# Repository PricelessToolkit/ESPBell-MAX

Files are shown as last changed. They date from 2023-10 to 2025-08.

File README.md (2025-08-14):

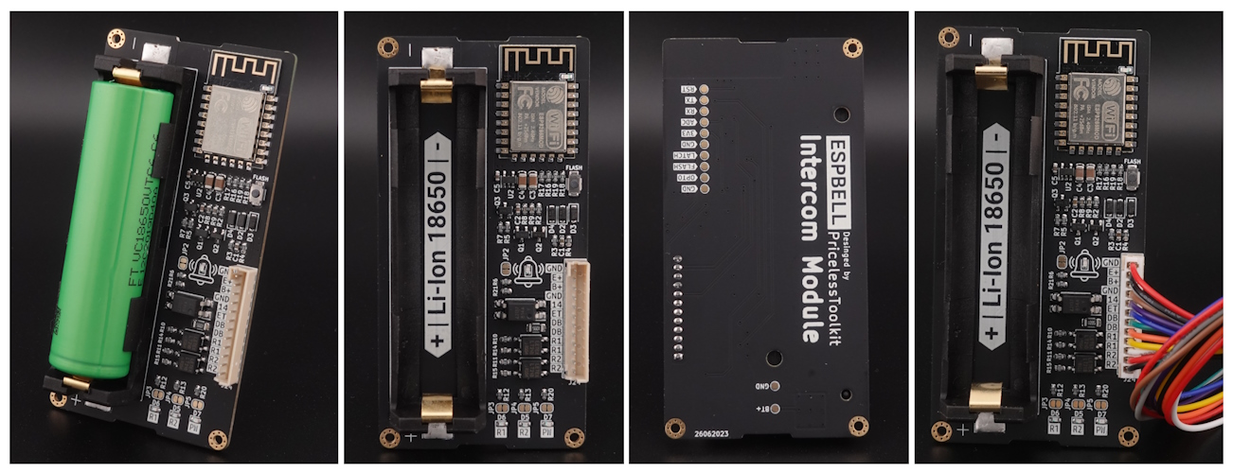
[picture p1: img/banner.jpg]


🤗 Please consider subscribing to my [YouTube channel](https://www.youtube.com/@PricelessToolkit/videos)
Your subscription goes a long way in backing my work.



# ESPBell-MAX and [ESPBell-LITE](https://github.com/PricelessToolkit/ESPBell-LITE)
ESPBell-MAX "IoT Intercom / Doorbell" module enables you to stay informed whenever someone rings your doorbell or presses the intercom button. Upon receiving an interactive notification, you have the convenience to either promptly open the door or choose to dismiss the alert by simply tapping the button within the notification. See the screenshot below.
<details>
  <summary>Notification Screenshot</summary>
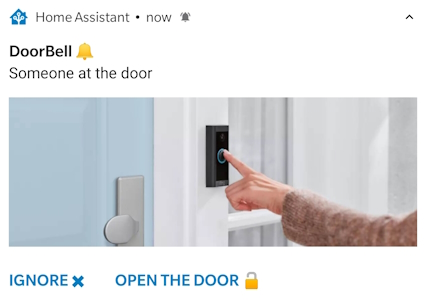
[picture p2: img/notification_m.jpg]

</details>

### _Supported software and future plans_
Currently supported `Home Assistant` and `MQTT` If I have time I'll add control by `Telegram` and `WhatsApp`

### Links

- YouTube video [How To](https://youtu.be/-lQ_mbuilic)
- My Shop
  - [ESPBell-MAX](https://www.pricelesstoolkit.com/en/projects/37-espbell-max-intercom-doorbell-module-0741049314467.html)
  - [UNIProg Programmer](https://www.pricelesstoolkit.com/en/projects/33-uniprog-uartupdi-programmer-33v.html)
- Aliexpress
  - Pogo pin Clamp Fixture
    - https://s.click.aliexpress.com/e/_Dm3ox9R
  - Battery
    - https://s.click.aliexpress.com/e/_DCEo23d
    - https://s.click.aliexpress.com/e/_DCRn6r5
  - Charger
    - https://s.click.aliexpress.com/e/_DeroSfz
    - https://s.click.aliexpress.com/e/_DmU1DXv
  - Vis and Insert "Optional for 3D Case"
    - 3 x Vis M2 4mm - https://s.click.aliexpress.com/e/_DFzWgSp
    - 3 x Insert M2(OD 3.2mm length 3.5mm) - https://s.click.aliexpress.com/e/_DkM0Kfb
  - Cable and connector
    - 1 x 12 Pin PH2.0mm cable https://s.click.aliexpress.com/e/_DdG8cCl
    - 1 x 12 Pin PH2.0mm connector "Straight" https://s.click.aliexpress.com/e/_DDWbwM5

____________

## Specifications
- Based on ESP12F "Programmable via pads on the PCB"
- Power consumption
  - Standby mode: 0.08mA "Per Month!"
  - When triggered: 21uA/s
- Input / Output
  - 2 x "R1/R2" SSR 2.4A 30v Max
  - 1 x "DB" Input Optocoupler 2-30v AC/DC Max "For Doorbell"
  - 1 x "ET" Input 3.3-5v DC Max "External Trigger"
  - 1 x "B+" Battery Voltage "Permanent output"
  - 1 x "E+" Battery Voltage "When ESPBell is enabled"
  - 1 x "GPIO14" 3.3v DC MAX
  - 2 x GND "Only! for ET/B+/E+/GPIO14"
- Status LEDs - Can be deactivated "PCB Jumper"
  - 1 x R1
  - 1 x R2
  - 1 x DoorBell
  - 1 x Power
  - 1 x On ESP module "Not used"
- Battery type Li-Ion 18650
- Button for flashing Firmware

____________

## 📣 Updates, Bugfixes, and Breaking Changes

> [!NOTE]
>  If you're ready to contribute to the project, your support would be greatly appreciated. Due to time constraints, I may not be able to quickly verify new "features" or completely new "code" functionality, so please create a new code/script in the new folder.

- **25.07.2024** - "Voltage divider resistor R8 is 100K or 42.2K"
  ```c
  // Battery Voltage Calculation
  // Orders before 15.07.2024 Please check the voltage divider value. "Marking on the resistor R8"
  
  // If "01D" R8 = 100K"
  int batteryPercentage = map(adcValue, 300, 410, 0, 100); // "Voltage divider R8-100K"
  
  // If "61C" R8 = 42.2K"
  int batteryPercentage = map(average, 670, 880, 0, 100);; // "Voltage divider R8-42.2K"
  ```

____________

## Before you start

> [!NOTE]
> ✅ Please [check your Intercom type.](https://www.intercomsrus.com/finder/) It needs to be a 5-wire intercom system.
> I hope that everything is crystal clear as I've made every effort to provide a step-by-step explanation of the setup process. If you have any further questions regarding the setup or require assistance with assembling a printed circuit board, feel free to join our [Facebook Group](https://www.facebook.com/groups/pricelesstoolkit) or open a new [discussion](https://github.com/PricelessToolkit/ESPBell-MAX/discussions) topic in the dedicated tab.

> [!IMPORTANT]
> If you're new to Arduino-related matters, please refrain from asking basic questions like "how to install Arduino IDE". There are already plenty of excellent tutorials available on the internet. If you encounter any issues, remember that providing detailed information about the problem will help me offer more effective assistance. More information equals better help!

> [!WARNING]
> I would strongly advise against attempting to assemble this PCB on your own if you have no experience "0%" in soldering, or working with ESP / Arduino boards.
> Connecting ESPBell-MAX to your intercom or doorbell demands a certain level of electronics expertise and the proficiency to utilize a multimeter effectively. Please be aware that I cannot assume responsibility for any errors or issues that may arise. My role is to provide guidance and advice to the best of my abilities.

____________

## PCB Assembly
This project is open-source, allowing you to assemble ESPBell-MAX on your own. To simplify this process, I've provided an "Interactive HTML Boom File" located in the PCB folder. This interactive file helps you identify where to solder each component and polarity, reducing the chances of errors to a minimum. But if you don't feel confident in assembling it yourself, you can always opt to purchase a pre-assembled board from my [Shop](https://www.pricelesstoolkit.com)

____________

## Schematic
<details>
  <summary>View schematic. Click here</summary>
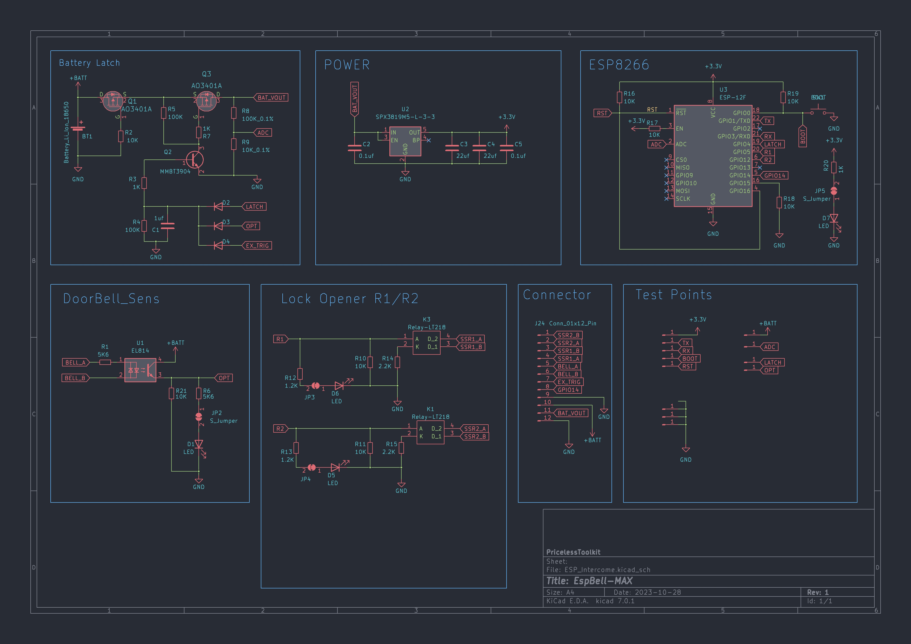
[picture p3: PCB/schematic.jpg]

</details>

____________

## Arduino IDE Configuration
### Used Arduino Libraries
```c
#include "ESP8266WiFi.h"
#include <PubSubClient.h>
```

If you are using ESP8266 for the first time, you need To install the ESP8266 board and PubSubClient library in your Arduino IDE.
- In your Arduino IDE, go to File> Preferences.
- Enter `http://arduino.esp8266.com/stable/package_esp8266com_index.json` into the “Additional Boards Manager URLs” field. Then, click the “OK” button
- Open the Boards Manager. Go to Tools > Board > Boards Manager.
- Search for ESP8266 and press the install button for the “ESP8266 by ESP8266 Community“
- Search for PubSubClient and press the install button.

For board configuration in IDE, see the screenshot below
<details>
  <summary>Board config Screenshot</summary>
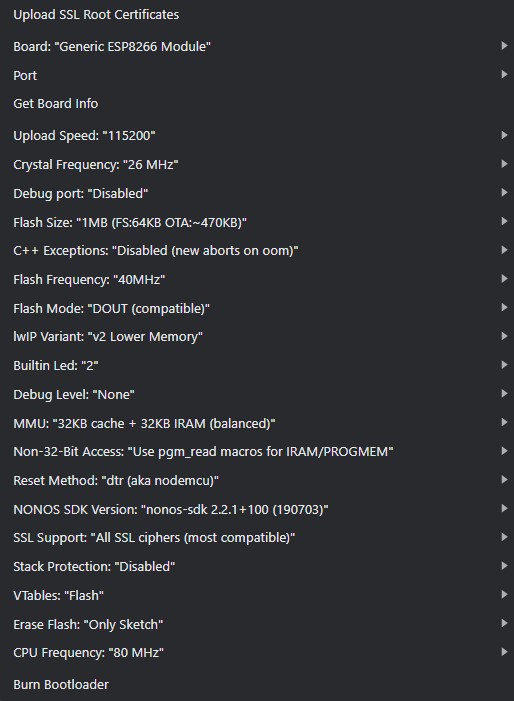
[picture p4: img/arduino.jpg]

</details>

____________

## ESPBell-MAX MQTT sketch configuration

> [!NOTE]
> For `ESPBell-MAX_MQTT_Auto_Discovery.ino`
> all configurations are done in the file `config.h`

### _WI-FI Settings_
To ensure a rapid Wi-Fi connection, we skip the Wi-Fi scanning process. Instead, we simply provide the access point's name, channel, and MAC address. This efficient method significantly shortens the connection time to the access point, taking just about 300 milliseconds.

> [!IMPORTANT]
> Make sure to set a fixed channel on your Wi-Fi access point.

```c
#define WIFI_SSID "Your_WIFI_SSID"
#define WIFI_AUTH "Your_WIFI_Password"
#define DATA_WIFI_CH 6 // Put your Wi-Fi channel and disable channel hopping in your WI-FI Access Point
#define DATA_WIFI_BSSID {0xAA, 0xAA, 0xAA, 0xAA, 0xAA, 0xAA} // Change only AA part.
```
### _Local Network Settings_
As the DHCP-based IP address assignment may introduce certain delays, we can optimize the process by manually assigning and registering the IP address.
> [!IMPORTANT]
> Use IP address outside of DHCP Range.

```c
// IP address, network mask, Gateway, DNS
#define DATA_IPADDR IPAddress(192,168,99,2) // Use IP address outside of DHCP Range 
#define DATA_IPMASK IPAddress(255,255,255,0)
#define DATA_GATEWY IPAddress(192,168,99,1)
#define DATA_DNS1   IPAddress(192,168,99,1)
```
### _MQTT Settings_
Fill in Mosquitto broker credentials and IP address.

```c
const char* mqtt_username = "Your_MQTT_Username";
const char* mqtt_password = "Your_MQTT_Password";
const char* mqtt_server = "IP_Address_of_MQTT/HomeAssistant";
const int mqtt_port = 1883;
```
### _Timing Settings_
Optimal performance and energy efficiency hinge upon these configurations, consisting of three critical parameters. It's important to note that 1000ms equates to 1 second.
<details>
  <summary>Explanation click here</summary>
upTime: This variable represents the time delay, in milliseconds, before initiating a 'Power Off' operation by setting the Latch PIN to LOW. You can adjust this value to determine how long the system should wait after waking up before powering down.

openTime: This variable sets the duration, in milliseconds, during which the relays remain active. Modify this value to control how long the relays stay on.

autoOff: This parameter can be set to either 0 or 1:
- 0: DISABLED - ESPBell will power down after the 'upTime' specified.
- 1: ENABLED - ESPBell will automatically power down after the 'openTime' has elapsed.
</details>

> [!IMPORTANT]
> When using ESPBell-MAX with an intercom system select your 'upTime' value carefully to ensure you have sufficient time for picking up your phone, checking notifications, and pressing the action button, along with a little extra time in reserve for added convenience. In the doorbell setup 2s 'upTime' is more than enough.

```c
// 1000 = 1s"
const long upTime = 15000;  // How long to wait after wakeup before powering off "Latch PIN to LOW" 
const long openTime = 2000;  // How long relays is on.
const int autoOff = 1; // 0 = DISABLE / 1 = ENABLE // Powering off automatically after "openTime" // if is set to 0 ESPBell will power down after upTime.
```

____________

## Uploading the Arduino sketch
To upload the sketch into ESPBell-MAX you will need two things.
- Regular USB-TTL 3.3v adapter. I have [open-source USB-TTL](https://github.com/PricelessToolkit/UNIProg_Programmer) project, in case you don’t have a TTL adapter yet and want to assemble it yourself.
- Pogo pin Clamp Fixture "single row 6 Pin 2.54mm spacing" or you can solder wires directly to ESPBell-MAX for programming.

### _USB-TTL Wiring diagram_

| USB-TTL | ESPBell-MAX |
| --- | --- |
| TX | RX |
| RX | TX |
| GND | GND |
| 3.3v | 3.3V |

You need to put the ESPBell-MAX into download mode to upload the firmware, for that, press and hold the Flash button on the ESPBell-MAX, then plug in the USB and press the upload button in Arduino IDE, Don't release the Flash button until you see the upload progress.
____________

## Home Assistant Configuration
> [!NOTE]
> After connection, Home Assistant will automatically  discover ESPBell-MAX with 3 sensors.
> - Bell    | Statuses is OPEN / CLOSE
> - RSSI    | in dBm
> - Battery | in percent 0-100% "3.2-4.2V"
> Because the ESP8266 ADC is inaccurate, measurements can fluctuate.

Here is a multi-user configuration example, which means that a notification is sent to several family members. If one family member clicks on the notification, the notification disappears from the other phones. For all this to work we need to create "three" automation, but before that, in this example, you need to change a minimum few things.
- Image file path that is used as a background for Notification.
- The name of the mobile device that is connected to the Home Assistant. In my case, it's "doogee_v20pro" and "Second_Phone"
  
```yaml
  image: /media/local/notify/doorbell.jpg
- service: notify.mobile_app_doogee_v20pro
- service: notify.mobile_app_Second_Phone

```

### _Automation 1_
This automation sends an interactive notification with the "tag: intercom" to phones.

<details>
  <summary>Explanation click here</summary>
  Alias: This is a user-defined name or label for the automation. In this case, it's given the name "🔔 Intercom DoorBell Notification," which suggests that it's related to receiving notifications for an intercom or doorbell event.

Description: This field is left empty, so there's no additional description provided for this automation.

Trigger: The trigger specifies the event or condition that will start the automation. In this case, it is triggered when the state of the "binary_sensor.espbell_max_bell" changes to "on." This implies that the automation will run when the binary sensor named "espbell_max_bell" switches from an off state to an on state.

Condition: There are no additional conditions specified. This means the automation will proceed without any additional conditions beyond the trigger.

Action: The action section defines what should happen when the trigger condition is met. In this case, there are two actions defined:

The first action uses the "notify.mobile_app_doogee_v20pro" service to send a notification to a mobile device. The notification includes a message "Someone at the door" and is configured with various data attributes, including a persistent notification, high importance, a specified channel ("intercom"), and a tag ("intercom"). It also includes an image file path for the notification and two actions that can be taken by the recipient: "Ignore ✖" and "Open The Door 🔓." The title and message of the notification are also specified in two languages (English and French).

The second action is similar to the first but uses the "notify.mobile_app_Second_Phone" service to send the same notification to another mobile device.

Mode: The mode is set to "single," which means that the automation will only run once for each trigger event. Subsequent trigger events will not cause the automation to run again until the current execution has been completed.
</details>

```yaml
alias: 🔔 Intercom DoorBell Notification
description: ""
trigger:
  - platform: state
    entity_id:
      - binary_sensor.espbell_max_bell
    to: "on"
condition: []
action:
  - service: notify.mobile_app_doogee_v20pro
    data:
      message: Someone at the door
      data:
        persistent: true
        importance: high
        channel: intercom
        tag: intercom
        image: /media/local/notify/doorbell.jpg
        actions:
          - action: intercom_ignore
            title: Ignore ✖
          - action: intercom_open
            title: Open The Door 🔓
      title: DoorBell 🔔
      message: Quelqu'un à la porte
  - service: notify.mobile_app_Second_Phone
    data:
      message: Someone at the door
      data:
        persistent: true
        importance: high
        channel: intercom
        tag: intercom
        image: /media/local/notify/doorbell.jpg
        actions:
          - action: intercom_ignore
            title: Ignore ✖
          - action: intercom_open
            title: Open The Door 🔓
      title: DoorBell 🔔
      message: Quelqu'un à la porte
mode: single

```

### _Automation 2_
This automation clears notifications with the "tag: intercom" on phones when an ignore button on the notification is pressed.

<details>
  <summary>Explanation click here</summary>
Alias: The alias is a user-defined name or label for the automation, and in this case, it's named "🔔 Intercom DoorBell ignore notification Dismiss." This name suggests that the automation is related to dismissing or ignoring notifications for an intercom or doorbell event.

Description: The description field is left empty, so there's no additional description provided for this automation.

Trigger: This automation is triggered by an event. The trigger condition is defined as follows:

platform: The trigger platform is "event," which means the automation will be triggered by an event.

event_data: The automation will only trigger when the event data contains a specific action. In this case, the trigger event is looking for events with the action "intercom_ignore."

event_type: The automation is tied to the "mobile_app_notification_action" event type. It implies that this automation is designed to respond to actions taken by the user within a mobile app notification.

Condition: There are no additional conditions specified. This means the automation will proceed without any additional conditions beyond the trigger.

Action: The action section specifies what should happen when the trigger condition is met. This automation has two actions:

The first action uses the "notify.mobile_app_doogee_v20pro" service to send a notification with the message "clear_notification." It also includes data attributes with the "tag" set to "intercom." This effectively clears or dismisses the notification with the "intercom" tag on the "mobile_app_doogee_v20pro" mobile app.

The second action is identical to the first but uses the "notify.mobile_app_Second_Phone" service to clear or dismiss the notification on another mobile device with the "intercom" tag.

Mode: The mode is set to "single," which means that the automation will only run once for each trigger event. Subsequent trigger events with the "intercom_ignore" action will trigger this automation, but it will only clear the notification once.
</details>

```yaml
alias: 🔔 Intercom DoorBell ignore notification Dismiss
description: ""
trigger:
  - platform: event
    event_data:
      action: intercom_ignore
    event_type: mobile_app_notification_action
condition: []
action:
  - service: notify.mobile_app_doogee_v20pro
    data:
      message: clear_notification
      data:
        tag: intercom
  - service: notify.mobile_app_Second_Phone
    data:
      message: clear_notification
      data:
        tag: intercom
mode: single
```

### _Automation 3_
This automatization enables the Relays R1/R2 by publishing the MQTT payload and clears notifications with the "tag: intercom" on phones when the notification button is pressed on one of the phones.
Solid-state relays are controlled by publishing the MQTT payload. MQTT Command Topic is "homeassistant/sensor/espbell-max/command" Payload is "00" The first digit is controlling R1 second digit R2.

* "01" R1=OFF R2=ON
* "11" R1=ON R2=ON
* "10" R1=ON R2=OFF
* "00" R1=OFF R2=OFF

```yaml
alias: 🔔 Intercom open the door and Dismiss notification
description: ""
trigger:
  - platform: event
    event_data:
      action: intercom_open
    event_type: mobile_app_notification_action
condition: []
action:
  - service: mqtt.publish
    data:
      qos: 0
      retain: false
      topic: homeassistant/sensor/espbell-max/command
      payload: "10"
  - service: notify.mobile_app_doogee_v20pro
    data:
      message: clear_notification
      data:
        tag: intercom
  - service: notify.mobile_app_Second_Phone
    data:
      message: clear_notification
      data:
        tag: intercom
mode: single

```

____________

## Power Behavior

By default, the device is designed to remain in a power-off state when not triggered. It is **not** meant to stay powered on continuously. Instead, it will automatically wake up, send the necessary data to Home Assistant, wait for the configured **"stay awake" duration** (as set in the firmware), and then return to power-off mode.

The ESPBell MAX wakes up (powers on) **only when**:

1. The **ET (External Trigger)** pin is momentarily connected to **B+**, or  
2. A doorbell signal is received via the **DB (Doorbell)** input pins.

This behavior ensures **long battery life** and is intentional by design.

## Wiring diagram ESPBell-Max to Intercom | Doorbell

### _Intercom_
<details>
  <summary>Differences Between 4+N and 1+N Intercom Systems. Click here</summary>

In the world of intercom systems, two common configurations stand out: 4+N and 1+N. Understanding the distinctions between these setups is crucial for successful installation and operation. Here's a quick overview:

4+N Intercom Systems:

In a 4+N system, the "4" signifies the presence of four distinct wires, each with a specific purpose.
These four wires are typically allocated as follows: one for the microphone, one for the speaker, one for the doorbell, and one for the lock.
Additionally, the "N" wire represents the neutral wire, which is used for the electrical current's return path.
4+N systems offer separate wiring and control for microphone, speaker, doorbell, and lock functions.

1+N Intercom Systems:

In contrast, a 1+N system streamlines the wiring process by combining audio communication and power supply over a single wire.
The "1" in 1+N indicates that one wire is used for both audio communication and power transmission.
Like 4+N systems, the "N" wire in 1+N systems also stands for the neutral wire.
1+N systems simplify wiring, using a single wire for audio and power, making installation more straightforward.

</details>

<details>
  <summary>4+N Intercom System wiring diagram. Click here</summary>
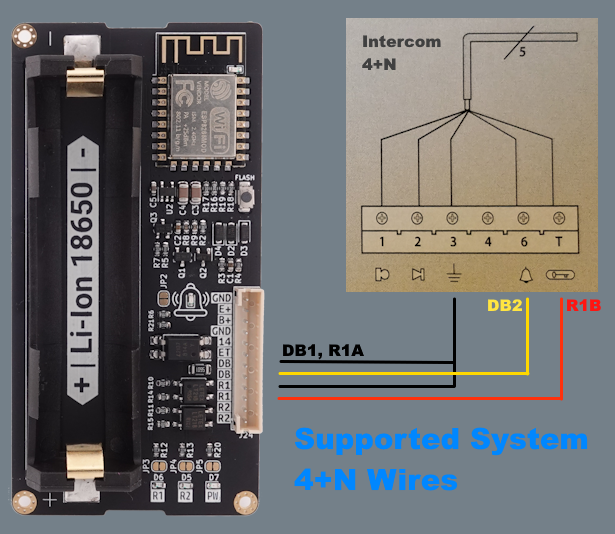
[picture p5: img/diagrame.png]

</details>

> [!NOTE]
> Currently, only the 4+N Intercom system is supported by ESPBell-MAX. But if you want you can connect ESPBell-MAX to the unsupported intercom buttons directly!

### _Doorbell_

<details>
  <summary>Dorbell wiring diagram. Click here</summary>
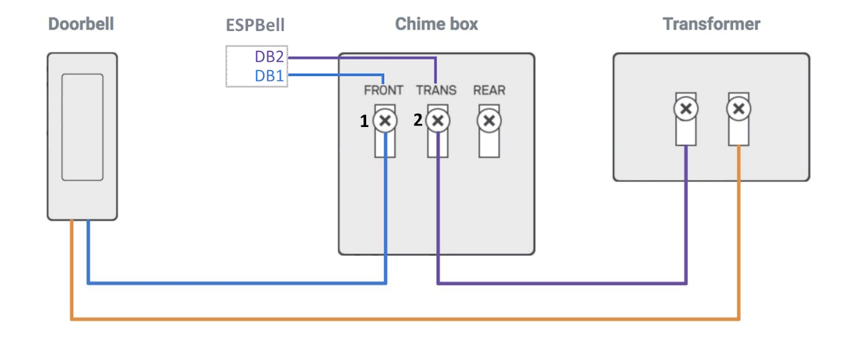
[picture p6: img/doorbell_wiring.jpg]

</details>

> [!WARNING]
> If there is current leakage between contacts 1 and 2 see "Dorbell wiring diagram" ESPBell may trigger randomly "The current flow may be due to the installed light bulb in the doorbell button which illuminates all the time" So before you start it’s better to check it with a multimeter.

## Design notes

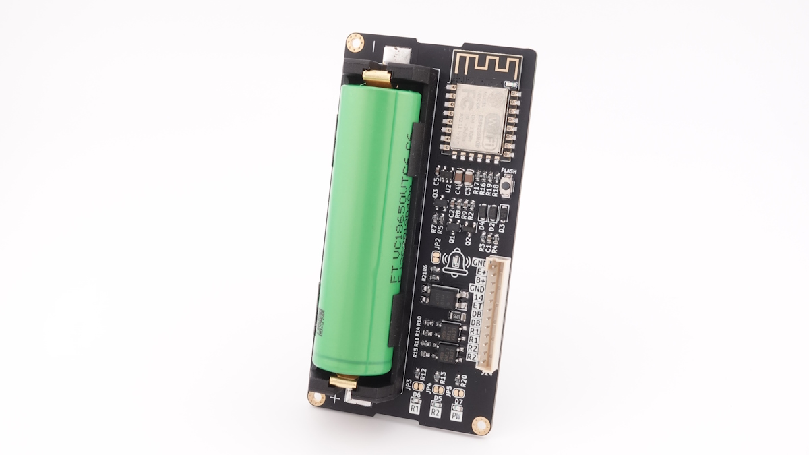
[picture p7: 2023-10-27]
img/ESPBell-MAX_2.JPG

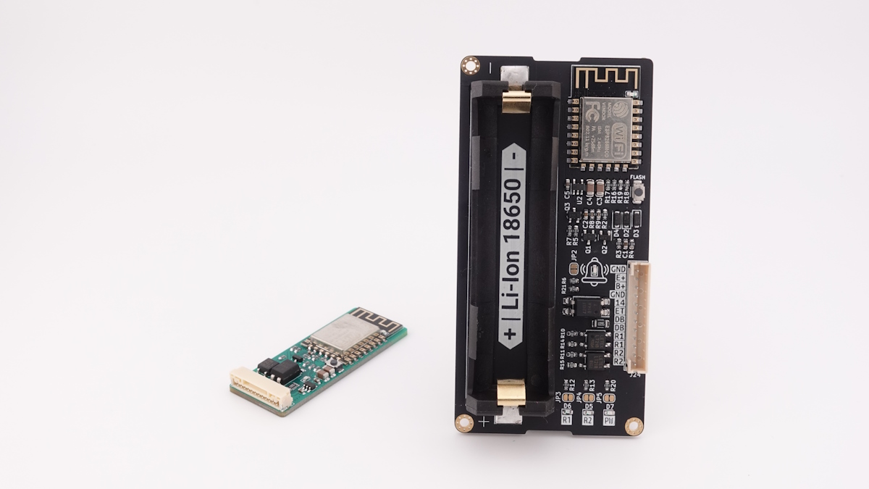
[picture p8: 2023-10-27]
img/ESPBell-MAX_3.JPG

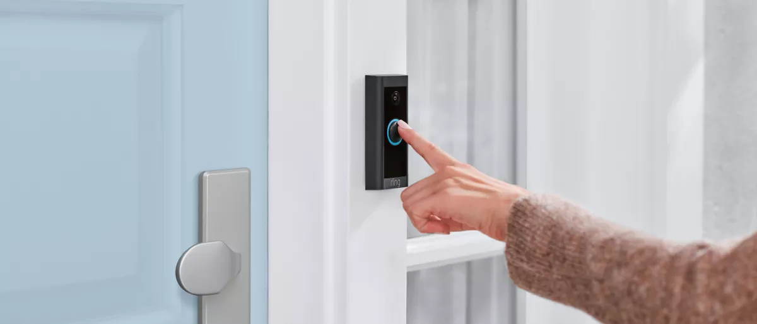
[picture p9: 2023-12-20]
img/doorbell.jpg

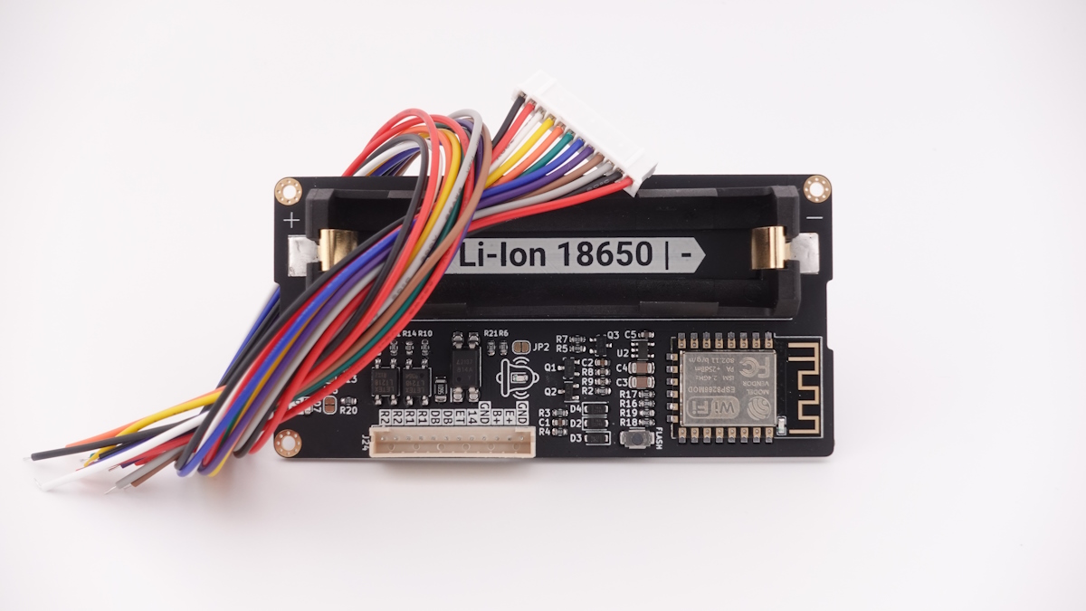
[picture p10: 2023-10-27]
img/ESPBell-MAX_4.JPG

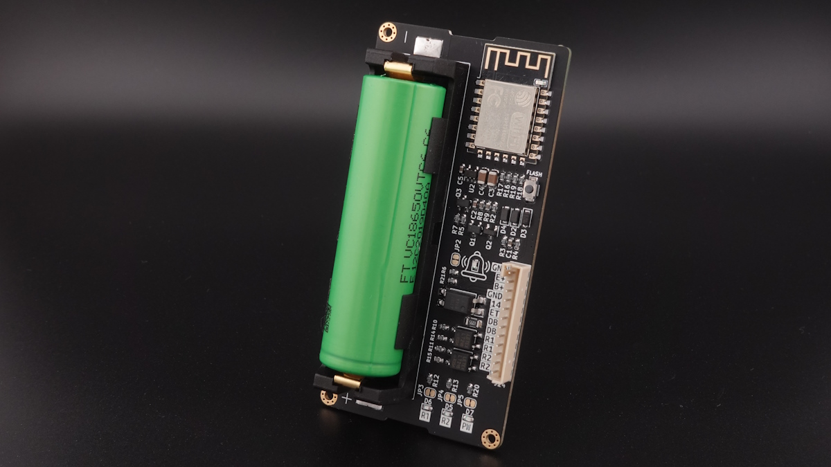
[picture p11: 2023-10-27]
img/ESPBell-MAX_1.JPG

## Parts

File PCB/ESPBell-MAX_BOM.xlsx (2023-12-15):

Part IPN | Part Name | Description | Quantity | Reference | Manufacturer_0 | MPN_0 | Supplier_0_0 | SKU_0_0 | Supplier_0_1 | SKU_0_1 | Manufacturer_1 | MPN_1 | Supplier_1_0 | SKU_1_0 | Supplier_0 | SKU_0
WIFI-000047-00 | WiFi Modules ESP8266_ESP-12F_PCBAntenna_2.4GHz - ROHS | 90dBm 16dBm ESP8266 PCBAntenna 2.4GHz SMD,16x24mm WiFi Modules ROHS | 1.0 | U3 | Ai-Thinker | ESP-12F(ESP8266MOD) | LCSC Electronics | C82891
CAP-000219-00 | Capacitor 0603_100nF_10%_50V_X7R - SMD/SMT ROHS | 50V 100nF X7R ±10% 0603 Multilayer Ceramic Capacitors MLCC - SMD/SMT ROHS | 2.0 | C2, C5 | YAGEO | CC0603KRX7R9BB104 | LCSC | C14663
CAP-000045-00 | Capacitor 1206_22uF_10%_25V_X5R - SMD/SMT ROHS | 25V 22uF X5R ±10% 1206 Multilayer Ceramic Capacitors MLCC - SMD/SMT ROHS | 2.0 | C3, C4 | Samsung Electro-Mechanics | CL31A226KAHNNNE | LCSC Electronics | C12891
RES-000267-00 | Resistor 0603_10K_1%_75V_100mW - Surface Mount ROHS | 100mW Thick Film Resistors ±100ppm/℃ ±1% 10kΩ 0603 Chip Resistor - Surface Mount ROHS | 9.0 | R2, R9, R10, R11, R16, R17, R18, R19, R21 | UNI-ROYAL(Uniroyal Elec) | 0603WAF1002T5E | LCSC | C25804 | LCSC Electronics | C25804
RES-000212-00 | Resistor 0603_1K_1%_50V_100mW - Surface Mount ROHS | 100mW ±100ppm/℃ ±1% 1kΩ 0603 Chip Resistor - Surface Mount ROHS | 5.0 | R3, R7, R12, R13, R20 | FH (Guangdong Fenghua Advanced Tech) | RS-03K1001FT | LCSC | C115325
RES-000216-00 | Resistor 0603_100K_1%_75V_100mW - Surface Mount ROHS | 100mW Thick Film Resistors ±100ppm/℃ ±1% 100kΩ 0603 Chip Resistor - Surface Mount ROHS | 3.0 | R4, R5, R8 | YAGEO | RC0603FR-07100KL | LCSC | C14675 | LCSC Electronics | C14675
RES-000028-00 | Resistors 0603_2.2K_1%_75V_100mW - Surface Mount ROHS | 100mW Thick Film Resistors ±100ppm/℃ ±1% 2.2kΩ 0603 Chip Resistor - Surface Mount ROHS | 2.0 | R14, R15 | UNI-ROYAL(Uniroyal Elec) | 0603WAF2201T5E | LCSC Electronics | C4190
RES-000051-00 | Resistor 1206_5.6K_1%_75V_250mW - Surface Mount ROHS | 250mW Thick Film Resistors ±100ppm/℃ ±1% 5.6kΩ 1206 Chip Resistor - Surface Mount ROHS | 1.0 | R1 | YAGEO | AC1206FR-075K6L | LCSC Electronics | C229724
RES-000016-00 | Resistor 0603_5.6K_5%_50V_250mW - Surface Mount ROHS | 250mW ±100ppm/℃ ±5% 5.6kΩ 0603 Chip Resistor - Surface Mount ROHS | 1.0 | R6 | UNI-ROYAL(Uniroyal Elec) | AS03W4J0562T5E | LCSC Electronics | C966164
DIO-000053-00 | LED 0603_55mW_Yellow-Green - ROHS | 2800K~3160K Colorless transparence -30℃~+85℃ Positive post 570nm~573nm Green/Yellow-Green 120° 55mW 0603 Light Emitting Diodes (LED) ROHS | 2.0 | D5, D6 | XINGLIGHT | XL-1608SYGC-06 | LCSC | C965805 | LCSC Electronics | C965805
DIO-000106-00 | Schottky Diode 1N5819W_40V_1A_SOD-123F (SBD) ROHS | 40V 600mV@1A 1A SOD-123F Schottky Barrier Diodes (SBD) ROHS | 3.0 | D2, D3, D4 | Shandong Jingdao Microelectronics | 1N5819W | LCSC Electronics | C169540
TRA-000108-00 | Optocoupler LTV-814S-TA1-A 35V 50mA AC,DC SMD-4P ROHS | 35V 5000V 50mA 0.1V@1mA,20mA 1 1.2V AC,DC SMD-4P Optocouplers - Phototransistor Output ROHS | 1.0 | U1 | Lite-On | LTV-814S-TA1-A | LCSC Electronics | C108051
PWR-000064-00 | Voltage Regulator SPX3819M5-L-3-3/TR 3.3V 500mA SOT-23-5 (LDO) ROHS | 500mA 70dB Fixed 3.3V Positive 16V SOT-23-5 Linear Voltage Regulators (LDO) ROHS | 1.0 | U2 | MaxLinear | SPX3819M5-L-3-3/TR | LCSC Electronics | C9055
MEC-000122-00 | Tactile Switche TS342A2P-WZ NO 50mA Brick nogging SPST SMD ROHS | NO 50mA 100MΩ 30000次 12V Brick nogging SPST SMD Tactile Switches ROHS | 1.0 | SW1 | SHOU HAN | TS342A2P-WZ | LCSC Electronics | C557591
TRA-000057-00 | Solid State Relay LT218_40V_2.5A_SOP-4 - ROHS | 1 Form A(SPST-NO) 1.2V 40V 0.06Ω 2.5A AC,DC SOP-4-2.54mm Solid State Relays - MOS Output (PhotoMOS) ROHS | 2.0 | K1, K3 | Letex | LT218 | LCSC Electronics | C2691607
TRA-000080-00 | MOSFET P-Channel AO3401A 30V 4.2A SOT-23 ROHS | 30V 4.2A 50mΩ@10V,4.1A 1.4W P Channel SOT-23 MOSFETs ROHS | 2.0 | Q1, Q3 | BORN | AO3401A | LCSC Electronics | C306862 |  |  | Alpha & Omega Semicon | AO3401A | LCSC Electronics | C15127
TRA-000038-00 | Bipolar Transistor MMBT3904_NPN_40V_200mA_SOT-23 - BJT ROHS | 40V 200mW 100@10mA,1V 200mA NPN SOT-23 Bipolar Transistors - BJT ROHS | 1.0 | Q2 | Jiangsu Changjing Electronics Technology Co., Ltd. | MMBT3904 | LCSC Electronics | C20526
CON-000056-00 | Connector 1x12P_PH-1_P2mm_2A_Male Wire To Board - ROHS | 1x12P PH 1 2mm Male pin 12 -25℃~+85℃ 2A Straight Plugin,P=2mm Wire To Board / Wire To Wire Connector ROHS | 1.0 | J24 | HCTL | HC-PH-12A-M | LCSC Electronics | C2979512
MEC-000259-00 | Battery Holder Keystone 1042 For 18650 SMD ROHS | BATT HOLDER 18650 1 CELL SMD | 1.0 | BT1 | Keystone Electronics | 1042 | Digi-Key | 36-1042-ND
CAB-000001-00 | Cable 1x12P PH 2.0mm 30cm | Wire to board cable with PH Connector 12 Pin | 1.0 | cable |  |  |  |  |  |  |  |  |  |  | Aliexpress | CABLE-1x12PH
CAP-000263-00 | Capacitor 0603_1uF_10%_25V_X7R - SMD/SMT ROHS | 25V 1uF X7R ±10% 0603 Multilayer Ceramic Capacitors MLCC - SMD/SMT ROHS | 1.0 | C1 | FH (Guangdong Fenghua Advanced Tech) | 0603B105K250NT | LCSC | C59302 | LCSC Electronics | C59302
DIO-000054-00 | LED 0603_55mW_Red 617nm~621nm - ROHS | Colorless transparence -30℃~+85℃ Positive post 617nm~621nm Red 120° 55mW 0603 Light Emitting Diodes (LED) ROHS | 1.0 | D7 | XINGLIGHT | XL-1608SURC-06 | LCSC Electronics | C965799
DIO-000201-00 | LED 0603_80mW_Blue XL-1608UBC-04 ROHS | Colorless transparence -30℃~+85℃ Positive post 460nm~469nm blue 120° 80mW 0603 Light Emitting Diodes (LED) ROHS | 1.0 | D1 | XINGLIGHT | XL-1608UBC-04 | LCSC | C965807

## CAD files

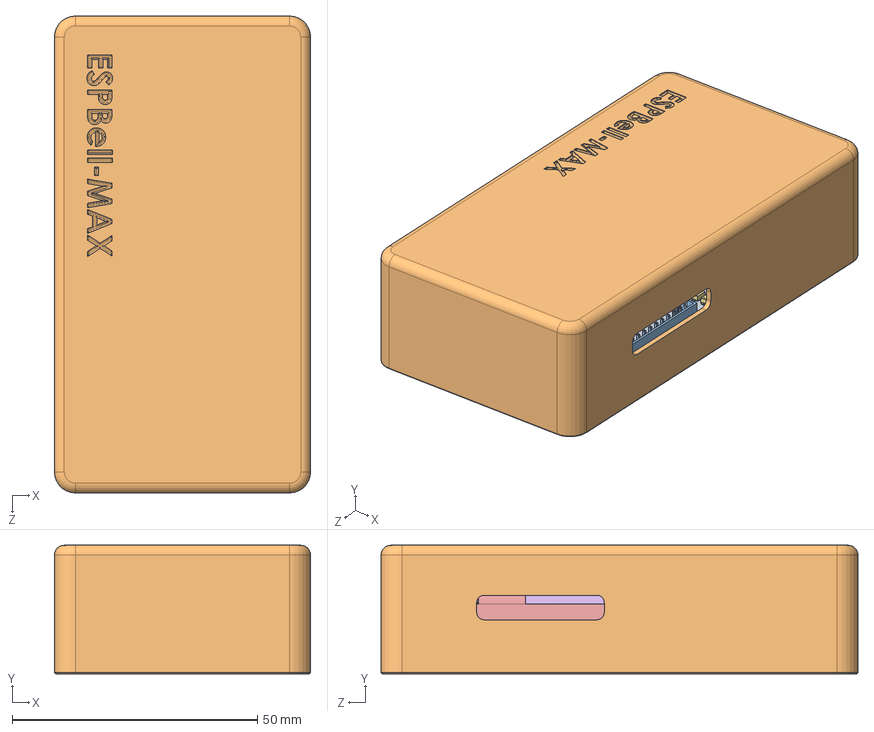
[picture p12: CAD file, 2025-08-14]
3D/Assem1.SLDASM
52.2 x 26.2 x 97.2 mm
Basse_Inserts
SOLID.step x 20
COMPOUND.step x 2
COMPOUND-0.step
SOLID-1.step x 3
SOLID-2.step x 2
SOLID-3.step x 3
SOLID-4.step
SOLID-5.step x 3
SOLID-6.step x 4
SOLID-7.step
SOLID-8.step
COMPOUND-9.step
COMPOUND-10.step
SOLID-11.step
COMPOUND-12.step
PCB.step
Cover

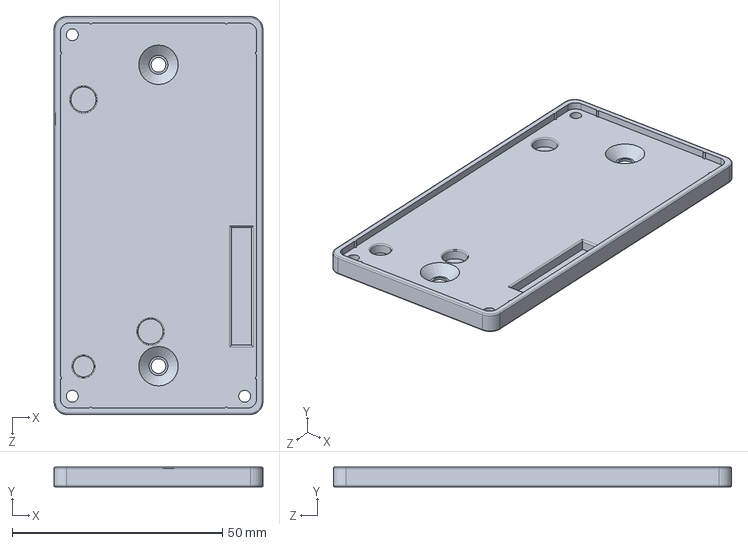
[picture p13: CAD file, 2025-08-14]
3D/Basse_Inserts.SLDPRT
49.7 x 4.70 x 94.7 mm

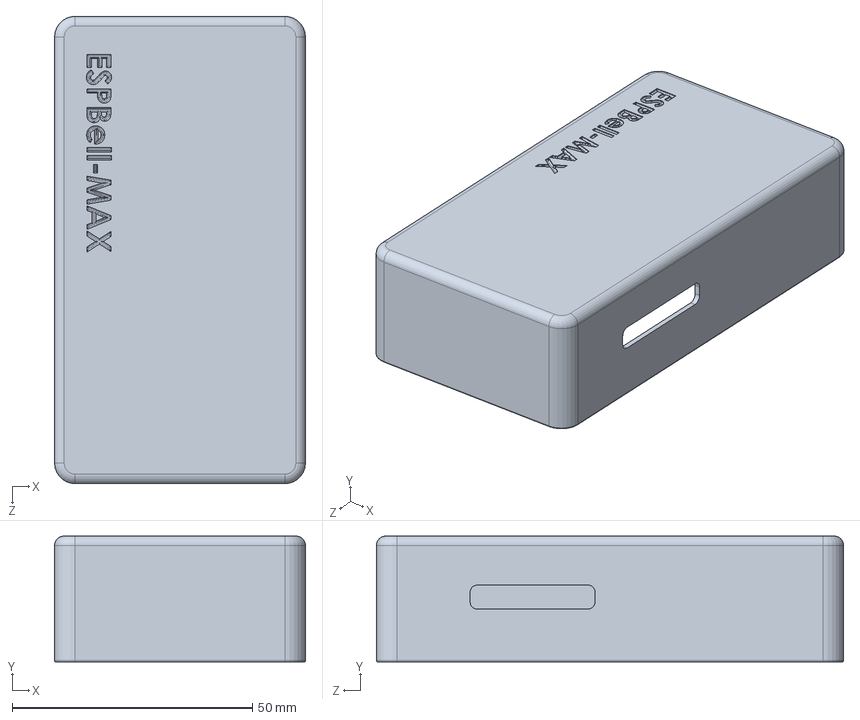
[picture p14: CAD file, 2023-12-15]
3D/Cover.SLDPRT
52.2 x 26.2 x 97.2 mm

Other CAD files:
3D/STL/Basse_Inserts.STL
3D/STL/Cover.STL

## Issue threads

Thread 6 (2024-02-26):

help on flashing please

thematrixdev, 2024-02-26:
Hello there.
I have got ESPBell-Max from your online store.
I have just got every hardware needed and started flashing.

I have installed Arduino IDE, ESP8266 boards and PubSubClient.
My OS is Ubuntu 23.10. Added user to `dialout` group and rebooted.
Plugging in the USB FTDI-USB, Arduino could identify `/dev/ttyUSB0`.

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

```
$ sudo dmesg -c
[ 2080.065194] usb 1-1: new full-speed USB device number 17 using xhci_hcd
[ 2080.220624] usb 1-1: New USB device found, idVendor=0403, idProduct=6001, bcdDevice= 6.00
[ 2080.220639] usb 1-1: New USB device strings: Mfr=1, Product=2, SerialNumber=3
[ 2080.220644] usb 1-1: Product: FT232R USB UART
[ 2080.220648] usb 1-1: Manufacturer: FTDI
[ 2080.220651] usb 1-1: SerialNumber: B001BPLG
[ 2080.224813] ftdi_sio 1-1:1.0: FTDI USB Serial Device converter detected
[ 2080.224840] usb 1-1: Detected FT232R
[ 2080.225207] usb 1-1: FTDI USB Serial Device converter now attached to ttyUSB0
```

Unplug FTDI-USB. Connect ESPBell-Max to FTDI-USB.
No matter with `flash` button pressed or not, plugging in FTDI-USB, `/dev/ttyUSB0` is not detected on Arduino IDE.

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

```
sudo dmesg -c
sudo dmesg -c
...
```

or

```
sudo dmesg -c
[ 2810.650571] usb usb1-port7: connect-debounce failed
```

Tried:
```
sudo systemctl stop ModemManager
sudo systemctl disable ModemManager
sudo reboot
```

I am using `RXD`, `TXD`, `GND` and `VCC`.
`VCC` is set to `3V3`.
FTDI-USB `RXD` to ESPBell-MAX `TX`.
FTDI-USB `TXD` to ESPBell-MAX `RX`.
FTDI-USB `GND` to ESPBell-MAX `GND`.
FTDI-USB `VCC` to ESPBell-MAX `3V3`.

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

Thanks.

PricelessToolkit, 2024-02-26:
Hi, I have never used Arduino IDE with Linux so I can't say anything, but If Arduino detects COM port only when USB-TTL is not connected to ESPBell, only one thing comes to mind USB-TTL adapter cannot provide enough power so voltage drops and adapter stop working, or connection is incorrect, can you check voltage when ESPBell is connected? And check the connection again, almost always these are simple errors that are difficult to notice.

thematrixdev, 2024-03-05:
> Hi, I have never used Arduino IDE with Linux so I can't say anything, but If Arduino detects COM port only when USB-TTL is not connected to ESPBell, only one thing comes to mind USB-TTL adapter cannot provide enough power so voltage drops and adapter stop working, or connection is incorrect, can you check voltage when ESPBell is connected? And check the connection again, almost always these are simple errors that are difficult to notice.

It works after getting another USB-TTL adapter:

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

I plan to use ESPBell-MAX with this doorbell:

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

Should I connect DB1 and DB2 on ESPBell-MAX to doorbell 1 and 3?
i.e.
DB1 -> 1 or DB1 -> 3
DB2 to the other

Thanks.

thematrixdev, 2024-03-05:
I am trying to wake up the board to see if the WIFI and MQTT configuration is correct.
Watching your Youtube video, shorting B+ and ET should power on the board.
However, mine did not power on.
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

PricelessToolkit, 2024-03-05:
It's strange, if you connect DB1 to battery + and DB2 to battery - like 0.5 seconds it wakes up?.

PricelessToolkit, 2024-03-05:
1 and 3 are the outside doorbell button wires Yes?

PricelessToolkit, 2024-03-05:
I think one DB to 3 and a second DB to upper contact from 3

thematrixdev, 2024-03-06:
> It's strange, if you connect DB1 to battery + and DB2 to battery - like 0.5 seconds it wakes up?.

No. I think it is physical issue on the board. Should I ship it back to you for checking?

Thanks.

PricelessToolkit, 2024-03-06:
Can you contact me from a shop so I can identify your order

thanks

thematrixdev, 2024-03-27:
I have got the replacement. It works with my doorbell now. Thank you very much!

Closed 2024-03-27.

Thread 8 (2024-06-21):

Arduino Verification step calls an error

s1ugh34d, 2024-06-21:
Arduino: 1.8.19 (Linux), Board: "Generic ESP8266 Module, 80 MHz, Flash, Disabled (new aborts on oom), Disabled, All SSL ciphers (most compatible), 32KB cache + 32KB IRAM (balanced), Use pgm_read macros for IRAM/PROGMEM, dtr (aka nodemcu), 26 MHz, 40MHz, DOUT (compatible), 1MB (FS:64KB OTA:~470KB), 2, nonos-sdk 2.2.1+100 (190703), v2 Lower Memory, Disabled, None, Only Sketch, 115200"

~/ESPBell-MAX_MQTT_Auto_Discovery/ESPBell-MAX_MQTT_Auto_Discovery.ino: In function 'void reconnect()':
ESPBell-MAX_MQTT_Auto_Discovery:81:15: error: 'class PubSubClient' has no member named 'setBufferSize'
   81 |     if(client.setBufferSize(380)){
      |               ^~~~~~~~~~~~~
exit status 1
'class PubSubClient' has no member named 'setBufferSize'

Should I just ignore this?

PricelessToolkit, 2024-06-21:
No, I am using Arduino IDE 2.3.2 on Windows, and it is compiling without errors. Please check if you have installed the libraries correctly.

ESP8266WiFi at version 1.0
PubSubClient at version 2.8

s1ugh34d, 2024-06-21:
I updated to 2.3.2 arduino and 2.8 PubSubClient and it verified fine, flash
success. The snap image on Ubuntu store is old for Arduino IDE.

Not code related but can the device be powered by the 3.3v input?

On Fri, Jun 21, 2024, 17:10 PricelessToolkit ***@***.***>
wrote:

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

PricelessToolkit, 2024-06-21:
Back side 3.3V? Yes but only for programming

Closed 2024-06-22.

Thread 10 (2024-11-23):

CPL File

Alejandro12120, 2024-11-23:
Hello, I was planning to order some assembled PCBs through a manufacturer, could you please upload the CPL file? Thanks

PricelessToolkit, 2024-11-23:
Hi, I don't share CPL files; only Gerber files and the BOM are provided for "self" assembly.

Closed 2024-11-23.

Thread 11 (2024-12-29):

Easily add support for 5+N Intercom

elektroman-23, 2024-12-29:
### Goal
I'd like to expand this project by either adding a second AC/DC optocoupler for a doorbell or by making the External Trigger AC-capable using a similar optocoupler.

### Why
My intercom has a 5th wire. That's because in our building there are [two doorbells](https://cdn.webshopapp.com/shops/260050/files/419710190/golmar-aansluitinformatie.pdf) per appartment.

One for when someone is downstairs at the door that I can open with the lock/buzzer.

And another doorbell right next to my own door (for when someone is already inside of the building (e.g. neighbours)).

As both doorbells work the same, based on the 12VAC signal from the transformer.

The second doorbell is often on a small PCB inside of the intercom in the appartement, which has a very annoying buzzer. It sounds like tinnitus.

This way we can have two doorbells. Then I could use the R1 and R2 to trigger a [doorbell speaker](https://www.google.com/search?q=honeywell+Honeywell+DC915SCV) for much nicer sounds and disctinct sounds based on what doorbell is rung.
I can also update the Home Assistant notification to indicate what bell was rung.

My idea is to make this available as a fork or second branch of this project, so users can choose what variant to use.
This is better than just to "copy" the PCB and keeping it to myself.

To do this I am kindly requesting @PricelessToolkit to make the kicad project available instead of just the gerber files. Or to implement this himself if he does not want to make the kicad project public.

Closed 2025-01-19.

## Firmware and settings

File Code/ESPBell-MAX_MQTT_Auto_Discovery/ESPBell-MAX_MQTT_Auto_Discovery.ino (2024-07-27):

#include "ESP8266WiFi.h"
#include <PubSubClient.h>
#include "config.h"

#define LATCH_PIN 4
#define R1_PIN 5
#define R2_PIN 12
bool retain = true;

unsigned long startMillis = 0;

unsigned long R1_startMillis;
unsigned long R1_currentMillis;
unsigned long R2_startMillis;
unsigned long R2_currentMillis;
int R1_oneshot = 0;
int R2_oneshot = 0;

WiFiClient espClient;
PubSubClient client(espClient);





int wifi_fast() {
  WiFi.persistent(true); 
  WiFi.mode(WIFI_STA);
  WiFi.config(DATA_IPADDR, DATA_GATEWY, DATA_IPMASK);
  uint8_t my_bssid[] = DATA_WIFI_BSSID;
  char my_ssid[] = WIFI_SSID;
  char my_auth[] = WIFI_AUTH;
  WiFi.begin(&my_ssid[0], &my_auth[0], DATA_WIFI_CH, &my_bssid[0], true);
  uint32_t timeout = millis() + 5000;
  while ((WiFi.status() != WL_CONNECTED) && (millis()<timeout)) { delay(5); }
  return (WiFi.status() == WL_CONNECTED);  
}




void callback(char* topic, byte* payload, unsigned int length) {
  Serial.print("Message arrived [");
  Serial.print(topic);
  Serial.print("] ");
  for (int i = 0; i < length; i++) {
    Serial.print((char)payload[i]);
  }
  Serial.println();

  // Switch on the R1 if an 1 was received as first character
  if ((char)payload[0] == '1') {
      digitalWrite(R1_PIN, HIGH); // Turn on the R1
      R1_startMillis = millis();
      R1_oneshot ++;

  } else {
    digitalWrite(R1_PIN, LOW);  // // Turn off the R1
  }



  // Switch on the R2 if an 1 was received as second character
  if ((char)payload[1] == '1') {
      digitalWrite(R2_PIN, HIGH);   // Turn on the R2
      R2_startMillis = millis();
      R2_oneshot ++;
    

  } else {
    digitalWrite(R2_PIN, LOW);  // Turn off the R2
  }

}


// Function to read the average of 20 ADC values
int getAverageADCReading() {
  int total = 0;
  for (int i = 0; i < 20; i++) {
    total += analogRead(A0);
  }
  int average = total / 20;
  return average;
}




void reconnect() {
  // Loop until we're reconnected
  while (!client.connected()) {
    Serial.print("Attempting MQTT connection...");
    if(client.setBufferSize(380)){
    Serial.println("Buffer Size increased to 380 byte"); 
    }else{
     Serial.println("Failed to allocate larger buffer");   
     }
    // Create a random client ID
    String clientId = "ESPBell-Max-";
    // Attempt to connect
    if (client.connect(clientId.c_str(),mqtt_username, mqtt_password)) {
        Serial.println("connected");
        // Once connected, publish an announcement...
  
        // Send auto-discovery message for doorbell, //device_class - I tried using switch but with it auto-discovery not working
        client.publish(
          "homeassistant/binary_sensor/espbell-max/state/config", 
          "{\"name\":\"Bell\",\"unit_of_measurement\":\"\",\"device_class\":\"door\",\"icon\":\"mdi:bell\",\"state_topic\":\"homeassistant/binary_sensor/espbell-max/state\",\"unique_id\":\"espbell-max_bell\",\"payload_on\":\"on\",\"payload_off\":\"off\",\"device\":{\"identifiers\":[\"espbell-max\"],\"name\":\"ESPBell-MAX\",\"mdl\":\"ESPBell-MAX\",\"mf\":\"PricelessToolkit\"}}",
          retain
        );

        // Send auto-discovery message for RSSI
        client.publish(
          "homeassistant/sensor/espbell-max/rssi/config",
          "{\"name\":\"RSSI\",\"unit_of_measurement\":\"dBm\",\"device_class\":\"signal_strength\",\"icon\":\"mdi:signal\",\"entity_category\":\"diagnostic\",\"state_topic\":\"homeassistant/sensor/espbell-max/rssi\",\"unique_id\":\"espbell-max_signal\",\"device\":{\"identifiers\":[\"espbell-max\"],\"name\":\"ESPBell-MAX\"}}",
          retain
        );

        // Send auto-discovery message for Battery %
        client.publish(
          "homeassistant/sensor/espbell-max/batt/config",
          "{\"name\":\"Battery\",\"unit_of_measurement\":\"%\",\"device_class\":\"battery\",\"icon\":\"mdi:battery\",\"entity_category\":\"diagnostic\",\"state_topic\":\"homeassistant/sensor/espbell-max/batt\",\"unique_id\":\"espbell-max_batt\",\"device\":{\"identifiers\":[\"espbell-max\"],\"name\":\"ESPBell-MAX\"}}",
          retain
        );

        // Send DoorBell Status "on"
        client.publish("homeassistant/binary_sensor/espbell-max/state", "on");
        

        
        // Reading and publishing RSSI Value
        String rs = String(WiFi.RSSI());
        client.publish("homeassistant/sensor/espbell-max/rssi", rs.c_str(), retain);



        int average = getAverageADCReading();
        //int batteryPercentage = map(average, 300, 410, 0, 100); // Orders before 15.07.2024 "Voltage divider R8-100K"
        int batteryPercentage = map(average, 670, 880, 0, 100);  // Orders after 15.07.2024 Hardware modification "Voltage divider R8-42.2K"
        int batteryP = constrain(batteryPercentage, 0, 100);
        client.publish("homeassistant/sensor/espbell-max/batt", String(batteryP).c_str(), retain);


        // Subscribing to Open command "R1/R2"
        client.subscribe("homeassistant/sensor/espbell-max/command");
     } else {
       Serial.print("failed, rc=");
       Serial.print(client.state());
       Serial.println(" try again in 0.05 seconds");
       // Wait 0.05 seconds before retrying
       delay(50);
    }
  }
}



void setup() {
  WiFi.setAutoConnect(false); // prevent early autoconnect
  pinMode(LATCH_PIN, OUTPUT);
  digitalWrite(LATCH_PIN, HIGH);
  pinMode(R1_PIN, OUTPUT);
  pinMode(R2_PIN, OUTPUT);

  //pinMode(LED_BUILTIN, OUTPUT);
  Serial.begin(115200);
  uint32_t ts_start = millis();
  int wifi_fast_ok = wifi_fast();
  //delay(500);
  //Serial.print("Timing wifi_fast(): ");
  //Serial.print(millis()-ts_start); Serial.println("ms");
  //Serial.print("Result="); Serial.println(wifi_fast_ok);

  client.setServer(mqtt_server, mqtt_port);
  client.setCallback(callback);
  startMillis = millis();
  
}




void loop() {

  if (!client.connected()) {
    reconnect();
  }
  client.loop();


  
  if(R1_oneshot >= 1){
    R1_currentMillis = millis();
    if (R1_currentMillis - R1_startMillis >= openTime){
      digitalWrite(R1_PIN, LOW); // Turn off the R1
      R1_oneshot = 0;
      if (autoOff == 1){
        client.publish("homeassistant/binary_sensor/espbell-max/state", "off", retain);
        delay(10);
        client.endPublish();
        digitalWrite(LATCH_PIN, LOW);
      }
    }
  }

  if(R2_oneshot >= 1){
    R2_currentMillis = millis();
    if (R2_currentMillis - R2_startMillis >= openTime){
      digitalWrite(R2_PIN, LOW); // Turn off the R2
      R2_oneshot = 0;
      if (autoOff == 1){
        client.publish("homeassistant/binary_sensor/espbell-max/state", "off", retain);
        delay(10);
        client.endPublish();
        digitalWrite(LATCH_PIN, LOW);
      }
    }
  }


  unsigned long currentMillis = millis();
  if (currentMillis + startMillis >= upTime) {
    // Reset doorbell status and command before poweroff
    client.publish("homeassistant/binary_sensor/espbell-max/state", "off", retain);
    delay(15);
    client.publish("homeassistant/sensor/espbell-max/command", "00", retain);
    delay(15);
    client.endPublish();
	delay(15);
    digitalWrite(LATCH_PIN, LOW);
    }
}

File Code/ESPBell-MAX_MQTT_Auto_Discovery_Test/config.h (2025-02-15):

// WiFi Configuration
#define WIFI_SSID "Your_WIFI_SSID"
#define WIFI_AUTH "Your_WIFI_Password"
#define DATA_WIFI_CH 6
#define DATA_WIFI_BSSID {0xAA, 0xAA, 0xAA, 0xAA, 0xAA, 0xAA} // Change the AA values as needed

// Network Settings: IP address, gateway, mask, DNS
#define DATA_IPADDR IPAddress(192,168,99,2) // Use an IP address outside the DHCP range
#define DATA_IPMASK IPAddress(255,255,255,0)
#define DATA_GATEWAY IPAddress(192,168,99,1)
#define DATA_DNS1   IPAddress(192,168,99,1)

// MQTT Credentials
const char* mqtt_username = "Your_MQTT_Username";
const char* mqtt_password = "Your_MQTT_Password";
const char* mqtt_server   = "MQTT/HomeAssistant_IP";
const int mqtt_port       = 1883;

// Timing settings (in milliseconds)
// upTime: Duration to wait after wakeup before powering off (Latch PIN to LOW)
const long upTime = 15000;
// openTime: Duration that the relay remains on
const long openTime = 2000;
// autoOff: 0 = DISABLE / 1 = ENABLE auto shutdown after openTime
const int autoOff = 1;

// Connection timeouts (in milliseconds)
// If the board cannot connect to WiFi within TimeToConnectWIFI, it powers off.
const long TimeToConnectWIFI = 30000;
// If the board cannot connect to the MQTT server within TimeToConnectMQTT, it powers off.
const long TimeToConnectMQTT = 40000;

// MQTT Command Topic: "homeassistant/sensor/espbell-max/command"
// Payload format (2 characters): first for R1, second for R2
// '1' = ON, '0' = OFF. Example: "11" turns both on, "10" turns R1 on and R2 off.

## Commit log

2023-10-28 Arduino IDE config
2023-12-20 Testing HA Device Class "running"
2024-07-25 "ADC" calculation
    Hardware modification
    // Orders before 15.07.2024 "Voltage divider R8-100K R9-10K"
    // Orders after 15.07.2024 "Voltage divider R8-30K R9-10K"
2024-07-25 ADC Values
2025-02-15 Added power-off max time for WiFi and MQTT, along with a couple of small modifications.
2025-08-14 Recess for Battery
    Recess for Original battery holder
    [Assem1.SLDASM, Basse_Inserts.SLDPRT, Basse_Inserts.STL]
